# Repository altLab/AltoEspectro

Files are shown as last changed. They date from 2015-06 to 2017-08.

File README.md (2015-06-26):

# AltoEspectro

Projecto de Uma Camara de CCD arrefecida para Espectroscopia, imagem de scanning, ou para fotografia panorâmica se utilizada com cabeça panorâmica.

Assenta no Sensor CCD da Sony ILX 544A com ultra sensibilidade.

Tendo como unidade de génese de sinais, leitura da saída do sensor, controlo do arrefecimento termoeléctrico, e controlo de temperatura o Microcontrolador da Atmel Atmega 328 que faz parte do Arduino Nano.

Notas do projecto podem ser encontradas no MicroSite de Documentação do AltLab 

[aqui](http://altlab.org/d/s/projectos/altspectra/)

Projecto Iniciado por:

- Fernando Carvalho
- JAC
- Luis Dinis
- Pedro Angelo

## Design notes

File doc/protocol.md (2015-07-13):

# AltSpectra serial protocol

The serial protocol uses a request/reply pattern between a host application and the device.

The host application issues commands that are comprised of a request header that identifies the command and an optional request payload (depending on the command)

    <header>[<data>]

The device replies with a reply header that indicates the request status followed by a data payload

    <header><data>

## Device Commands

### Init

Initialises the device

Request data: none <BR>
Reply status: OK/NOK <BR>
Reply data: firmware version <BR>

### Set Timestamp

Sets the internal timestamp

Request data: new timestamp in Julian Day with only the day part, and the time part = 0,500000 <BR>
Reply status: OK/NOK <BR>
Reply data: internaltime <BR>

### Get Spectrum Sample 

Get a spectrum sample from the sensor

Request data: exposure time in milliseconds <BR>
Reply status: OK/NOK <BR>
Reply data: sample timestamp, temperature readings (sensor and heatsink), data samples <BR>

### Halt Spectrum Sample

instructs device to Halt exposure.

Request data: none <BR>
Reply status: OK/NOK <BR>
Reply data: None <BR>

### Get Temperature Sample

Get the temperature values from the device

Request data: none <BR>
Reply status: OK/NOK <BR>
Reply data: temperature readings (sensor and heatsink) <BR>

### Set Temperature

Set the temperature values for the device

Request data: Temperature in Signed Decimal Format with 1 Decimal Digit <BR>
Reply status: OK/NOK <BR>
Reply data: temperature readings (sensor and heatsink) <BR>

### Set Cooling ON/OFF

Set the cooler on or OFF

Request data: "AS+F ON/OFF" <BR>
Reply status: OK/NOK <BR>
Reply data: Cooling Status {ON/OFF}; <BR>

### Get Cooling Status

Get the Cooler Status ON/OFF 

Request data: None <BR>
Reply status: OK/NOK <BR>
Reply data: Cooling Status TRUE:FALSE; <BR>

###Get Status

gets the internal Status of the device

Request data: NULL<BR>
Reply status: OK/NOK <BR>
Reply data: <Version> <timestamp> <coolingtemperature> <heatsinktemperature> <exposing> <cooling> <fan> <BR>

###Set Fan

Sets the Fan ON or OFF

Request data: ON/OFF <BR>
Reply status: OK/NOK <BR>
Reply data: Fan ON/OFF; <BR>

## Text Encoding

### Init

Request: "AS+A"

Reply: "OK firmware version CR "

### Set Timestamp

Request: "AS+B <timestamp>" <BR>
Reply: "OK <timestamp> <CR>" <BR>

### Get Spectrum Sample

Request: "AS+C <exposure time>" <BR>
Reply: "OK <timestamp> <sensor temperature> <heatsink temperature> <exposure> <data0> <data1> ... <data_n> <CR>" <BR>

### Halt Spectrum Sample

Request: "AS+D" <BR>
Reply: OK/NOK <BR>

### Get Temperature Sample

Request: "AS+E" <BR>
Reply: "OK <timestamp> <sensor temperature> <heatsink temperature> <CR>" <BR>

### Set Temperature

Request: "AS+F <sensor temperature>" <BR>
Reply status: OK <sensor temperature> <BR>
Reply data: "OK <sensor temperature> <heatsink temperature> <CR>" <BR>

### Set Cooling ON/OFF

Request data: "<AS+G ON/OFF>" <BR>
Reply status: OK/NOK <BR>
Reply data: "OK <sensor temperature> <heatsink temperature> <CR>" <BR>

### Get Status

Request data: "<AS+H>" <BR>
Reply status: OK/NOK <BR>
Reply data: "OK <version> <timestamp> <sensor temperature> <heatsink temperature> <CR>" <BR>

## Binary Encoding

### Init

Request: 0xA501
Reply: 0xA511 (OK) | 0xA510 (NOK) <firmware version (char / 1 byte)>

### Set Timestamp

Request: 0xA502 <timestamp (long int / 4 bytes)>
Reply: 0xA521 (OK) | 0xA520 (NOK)

### Get Spectrum Sample

Request: 0xA503 <exposure time (long int / 4 bytes)>
Reply: 0xA531 (OK) | 0xA5 (NOK) <timestamp (long int / 4 bytes)> <sensor temperature (short int / 2 bytes)> <heatsink temperature (short int / 2 bytes)> <data0 (short int / 2 bytes)> ... <data_n (short int / 2 bytes)>

### Get Temperature Sample

Request: 0xA504 
Reply: 0xA541 (OK) | 0xA540 (NOK) <sensor temperature (short int / 2 bytes)> <heatsink temperature (short int / 2 bytes)>

### Set Temperature

Request: 0xA505 <sensor temperature>"
Reply status: OK <sensor temperature>
Reply data: "OK <sensor temperature> <heatsink temperature> <CR>"

### Set Cooling ON/OFF

Request data: 0xA506 
Reply status: OK/NOK
Reply data: "OK <sensor temperature> <heatsink temperature> <CR>"

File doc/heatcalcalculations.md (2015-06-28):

#Calculo da capacidade térmica de um dissipador de aluminio:

##requisitos:

- Conductividade térmica do material do dissipador
- volume do dissipador.
- Diferencial de temperatura dos meios em contacto

##introdução

A propriedade intrinseca dos materiais que nos permite compreender como funciona um sistema de arrefecimento. Esta compreensão permite que em cenários complexos construir um sistema de arrefecimento mais ou menos eficiente, se utilizados os materiais correctos da forma correcta.

É necessário compreender que os detalhes ditam o sucesso ou o insucesso, não os ter em conta, reduz o desenho de sistemas de arrefecimento a uma mera adivinhação.

Os sistemas de arrefecimento, obedecem a leis que se podem aproximar a sistemas hidraúlicos na medida em que lidamos com quantidades, que tem de percorrer conductas sólidas, com propriedades que definem fluxos, logo a não compreensão destes fenómenos governadas por estas leis implica, a não realização de sistemas eficientes.

posto isto, coloquemos o contexto da construção de um sistema de arrefecimento para um arrefecedor termoeléctrico, baseado nos dispositivos TEC/Peltier que tiram partido do efeito de Sebbeck.

![Fotografia de um Peltier]()

O Peltier possui um lado quente e um lado frio, o primeiro dissipa o calor retirado do lado frio, criando um diferencial de temperatura, que pode atingir os 85 graus em determinados dispositivos.

A função do dissipador de um sistema destes visa conduzir em primeiro lugar o calor gerado na superficie do Peltier até ao ar que circunda o dispositivo. À priori parecerá simples, apenas temos de colocar um dissipador encostado ao peltier e obteremos a máxima eficiência, nada mais errado, estariamos a abordar o problema de forma ingénua e simplista, ao ponto de deixarmos de lado detalhes tão importantes como: a superficie de contacto, peltier com o dispositivo a arrefecer, entre a superficie a arrefecer e o sensor, o contacto do lado quente do peltier com o dissipador.

Em primeiro lugar é necessário perceber que o ar se encontra na equação em determinados pontos de contacto, pois as superficies por mais polidas que sejam possuem uma rugosidade onde se encontrará um isolante térmico dos mais eficientes, o ar. em segundo lugar se colocarmos um material que aumente a condução térmica, rápidamente reduziremos a resistência ao fluxo de calor. posteriormente, temos de compreender que um fluxo de ar no dissipador, deve ser suficiente para retirar o calor acumulado num dissipador por forma a aumentar a sua eficiência.

contemplemos o Dissipador no seu contacto com o ar, temos um material com um capacidade de condução térmica de aproximadamente 160 W. m-1 K-1, em contacto com um material, o ar, com uma capacidade de condução térmica, baixa, de 0.0262 W.m-1.K-1 logo um conductor térmico e uma fronteira para um isolante térmico, no entanto, é para este isolante térmico que temos que passar o calor. Para aumentar a eficiência desta transferêcia de calor temos de aumentar a razão de transferência, e usualmente esse aumento obtém-se aumentado a velocidade do fluxo de ar que permite retirar maior quantidade de calor. outra abordagem simples passa pelo aumento da superficie de contacto, que em hidráulica significaria o aumento da conduta de transferência, usualmente este concretização obtém com a mudança de um dissipador de laminas para um dissipador de pinos, ao duplicar a área do dissipador duplica-se a taxa de transferência de calor.

##Escolha do material do cold Finger:

A escolha do material do cold finger, foi realizada comparando os materiais disponíveis, cobre e aluminio, se à priori pareceria que o aluminio se apresentaria como um bom candidato, rápidamente ficou relegado para segundo lugar pela capacidade que possui de transmitir calor como se pode ver na tabela apresentada em 
[1].

Comparando a conductividade térmica de ambos se compreende que para o aluminio temos uma conductividade térmica de 249 W. m-1 Kelvin -1 e que para o Cobre temos um valor de 368 W.m-1.K-1, estando apenas a ter em linha de conta materiais puros, se pesquisarmos diferentes materiais disponíveis no mercado, concluimos que dependendo do grau de pureza da liga disponivel para aquisição temos ainda piores valores de conductividade térmica. Mamtém-se no entanto, o diferencial, ficando o cobre sempre na dianteira.

nesta comparação apenas compreendemos ser o cobre o elemento de eleição para a condução térmica do calor no caso do coldfinger, e no dissipador, no entanto a escolha deste elemento para o dissipador iria onerar muito os custos de produção de um dispositivo, como o que actualmente se encontra em desenvolvimento.

Compreender o Processo de transferência térmica e os factores que o influênciam:

Os factores que influênciam a transferência de calor são:

- Temperatura ambiente
- Humidade 
- Pressão Atmosférica.
- velocidade do Ar no dissipador
- Eficiência térmica do Peltier
- Eficiência térmica do conjunto de dissipação.

##Referências:

- [1] Listas de conductividades térmicas - https://en.wikipedia.org/wiki/List_of_thermal_conductivities
- Conversão de Watt para Joule - http://www.rapidtables.com/convert/electric/Watt_to_Joule.htm
- Conversãod e Joule para Grau Celsius - http://www.convertunits.com/from/joule/to/celsius+heat+unit
- peltier Guide - http://www.heatsink-guide.com/peltier.htm
- Thermoelectric Cooling - https://en.wikipedia.org/wiki/Thermoelectric_cooling
- Thermal Design - http://www.smps.us/thermal.html
- Novel Concept Heat Sink CFD Simulations . http://www.novelconceptsinc.com/heat-sinks.htm

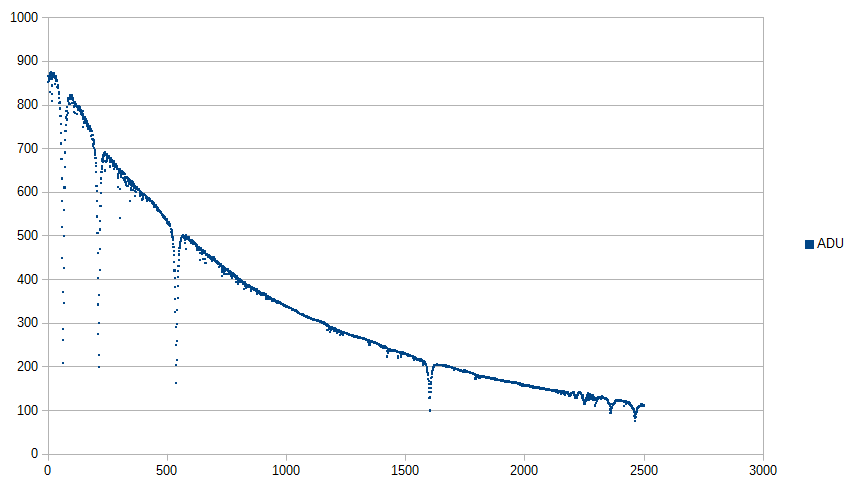
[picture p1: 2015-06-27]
doc/SampleData.png

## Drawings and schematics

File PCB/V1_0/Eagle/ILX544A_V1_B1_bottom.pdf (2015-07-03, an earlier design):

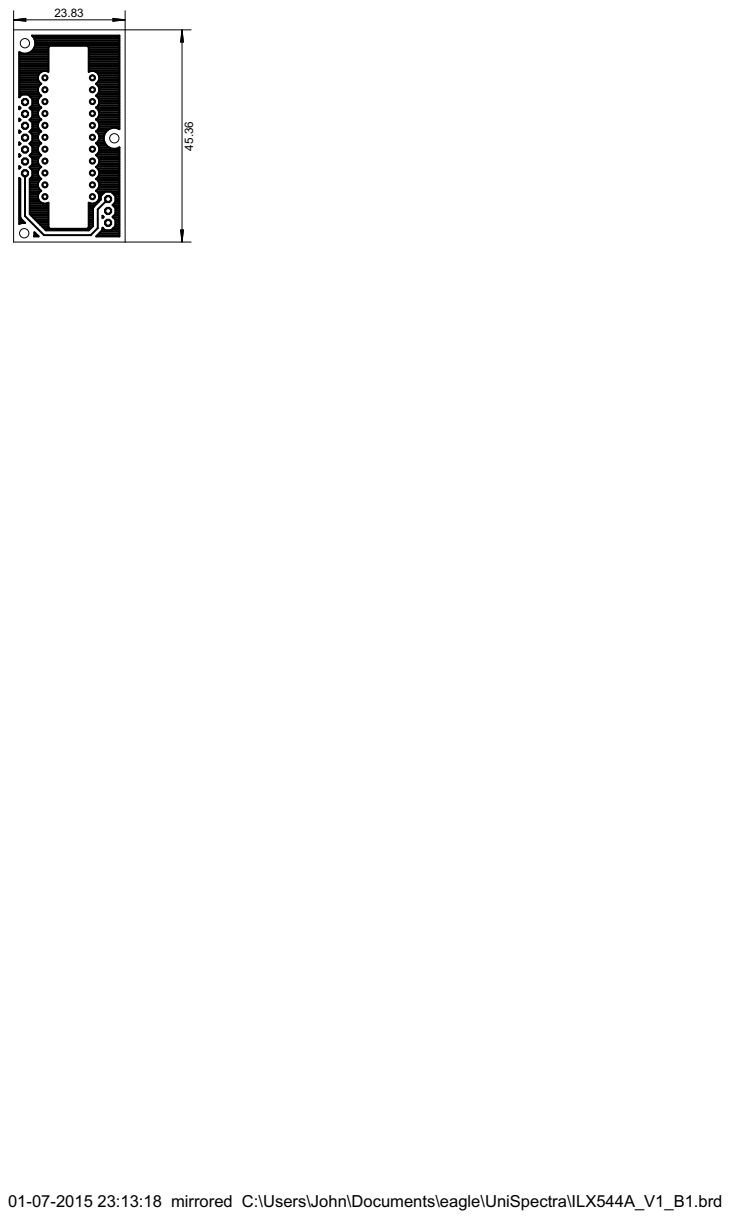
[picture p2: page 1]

01-07-2015 23:13:18 mirrored C:\Users\John\Documents\eagle\UniSpectra\ILX544A_V1_B1.brd

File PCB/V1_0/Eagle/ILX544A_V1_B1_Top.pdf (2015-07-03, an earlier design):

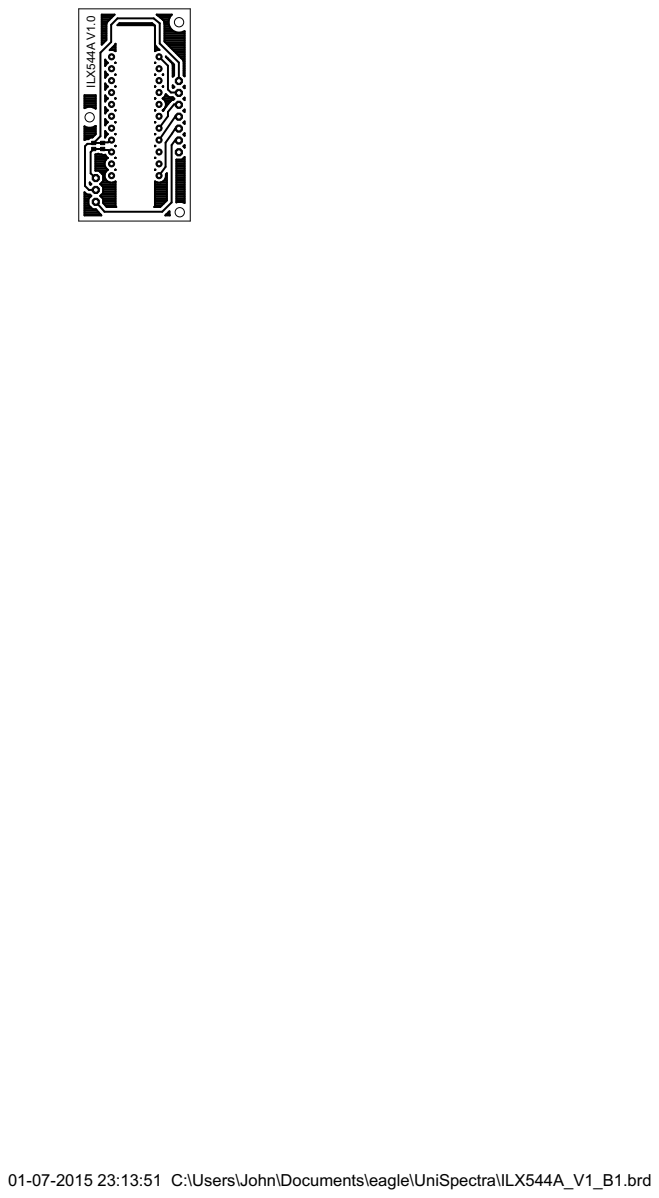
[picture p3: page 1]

01-07-2015 23:13:51 C:\Users\John\Documents\eagle\UniSpectra\ILX544A_V1_B1.brd

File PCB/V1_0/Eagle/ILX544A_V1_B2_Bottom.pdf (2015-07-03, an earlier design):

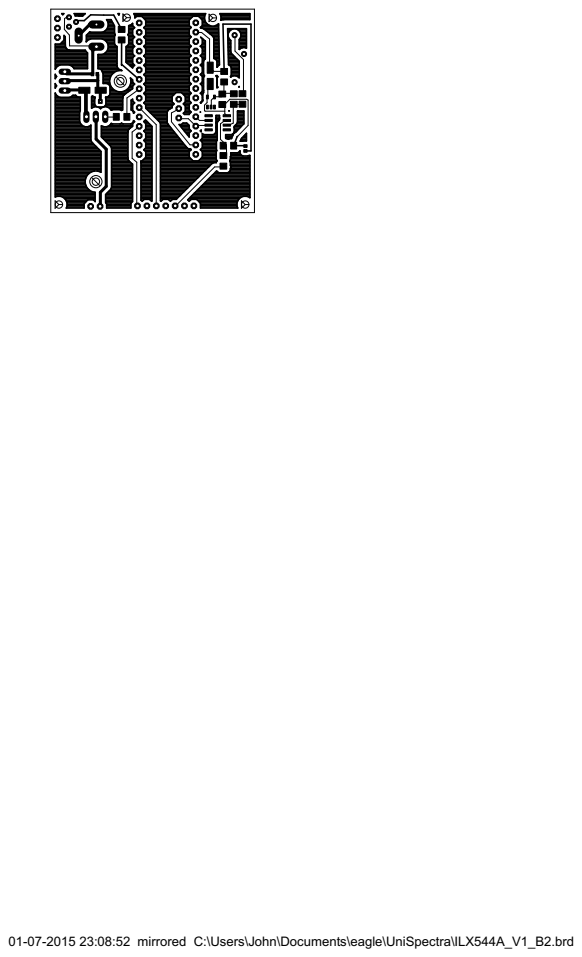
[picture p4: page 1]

01-07-2015 23:08:52 mirrored C:\Users\John\Documents\eagle\UniSpectra\ILX544A_V1_B2.brd

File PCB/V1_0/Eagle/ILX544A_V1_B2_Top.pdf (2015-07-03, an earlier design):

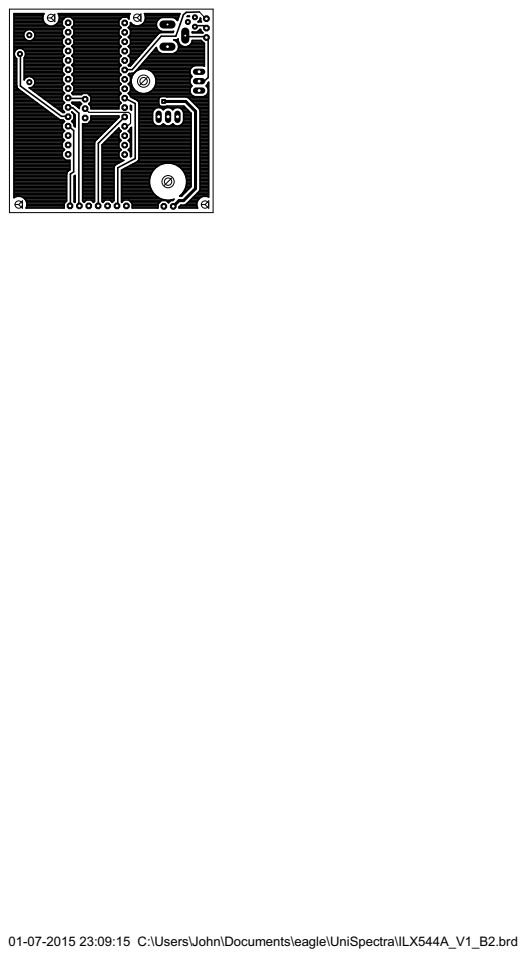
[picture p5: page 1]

01-07-2015 23:09:15 C:\Users\John\Documents\eagle\UniSpectra\ILX544A_V1_B2.brd

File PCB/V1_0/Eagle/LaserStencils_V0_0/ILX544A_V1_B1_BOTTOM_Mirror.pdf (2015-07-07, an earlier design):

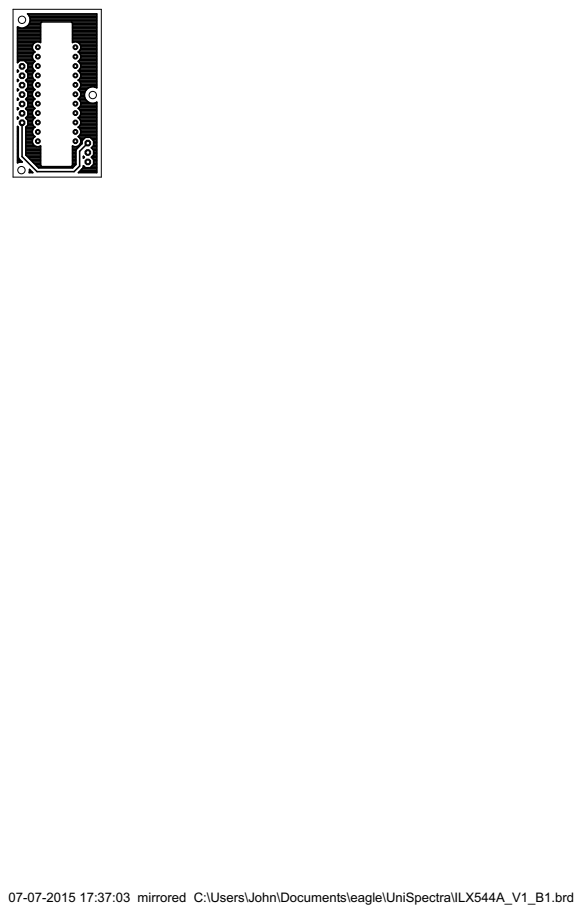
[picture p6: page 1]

07-07-2015 17:37:03 mirrored C:\Users\John\Documents\eagle\UniSpectra\ILX544A_V1_B1.brd

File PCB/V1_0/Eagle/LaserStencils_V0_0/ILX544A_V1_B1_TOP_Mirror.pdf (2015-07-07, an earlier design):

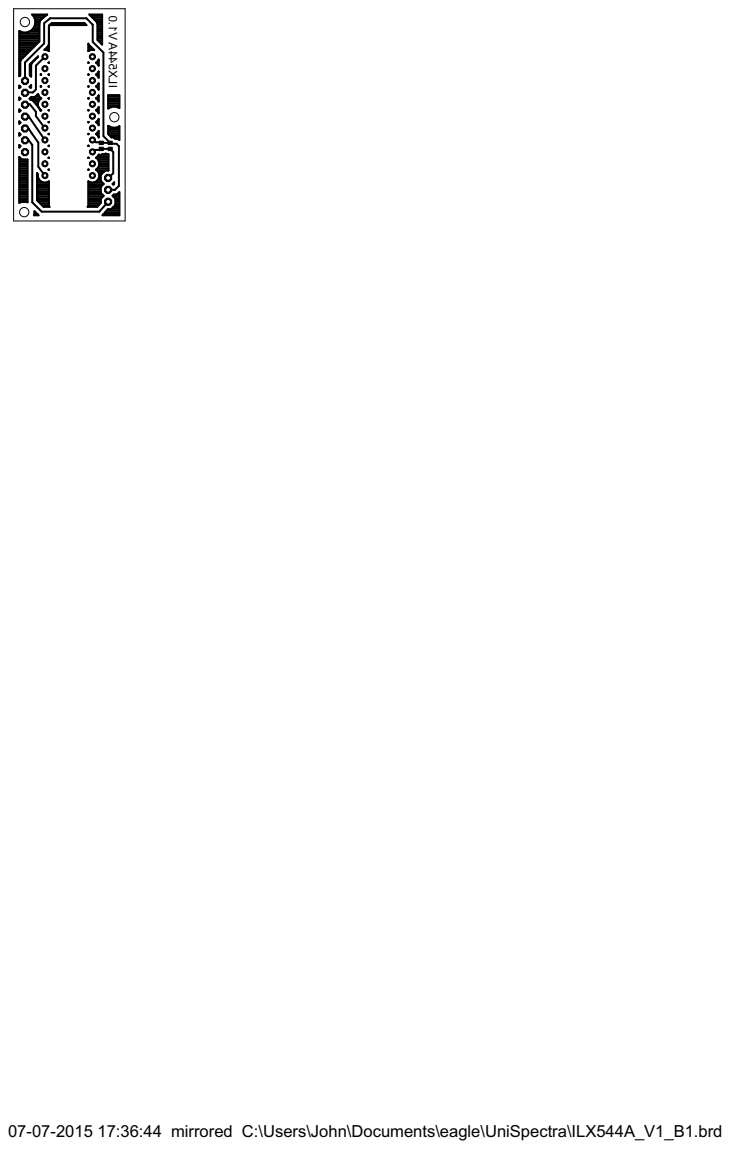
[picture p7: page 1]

07-07-2015 17:36:44 mirrored C:\Users\John\Documents\eagle\UniSpectra\ILX544A_V1_B1.brd

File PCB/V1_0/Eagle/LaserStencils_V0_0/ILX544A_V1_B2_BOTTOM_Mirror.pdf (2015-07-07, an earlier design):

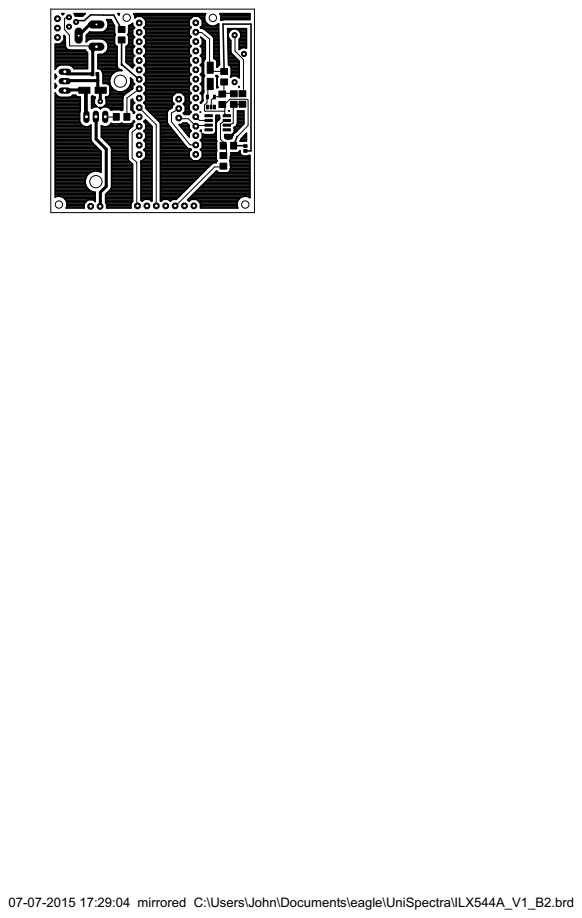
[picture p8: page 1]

07-07-2015 17:29:04 mirrored C:\Users\John\Documents\eagle\UniSpectra\ILX544A_V1_B2.brd

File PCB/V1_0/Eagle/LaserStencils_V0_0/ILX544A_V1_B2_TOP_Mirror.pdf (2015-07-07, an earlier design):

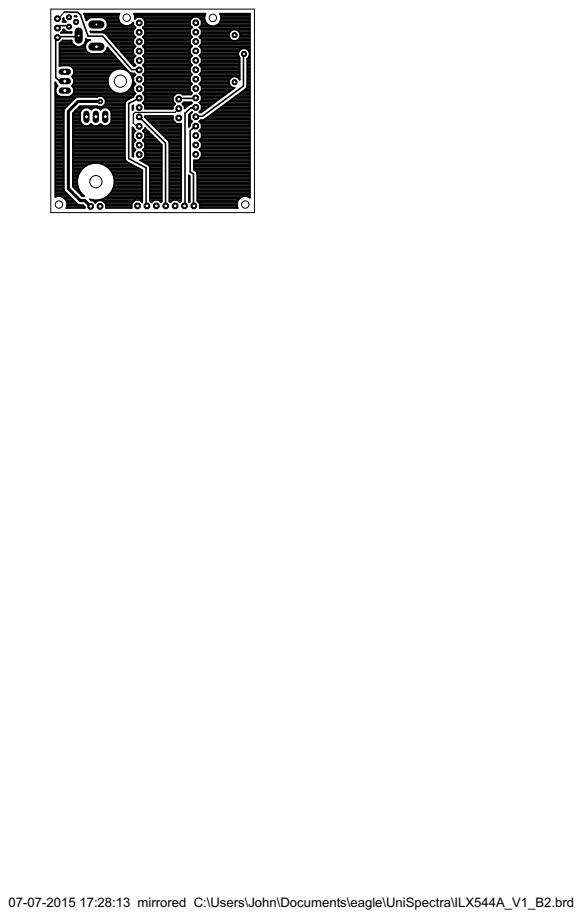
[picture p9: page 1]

07-07-2015 17:28:13 mirrored C:\Users\John\Documents\eagle\UniSpectra\ILX544A_V1_B2.brd

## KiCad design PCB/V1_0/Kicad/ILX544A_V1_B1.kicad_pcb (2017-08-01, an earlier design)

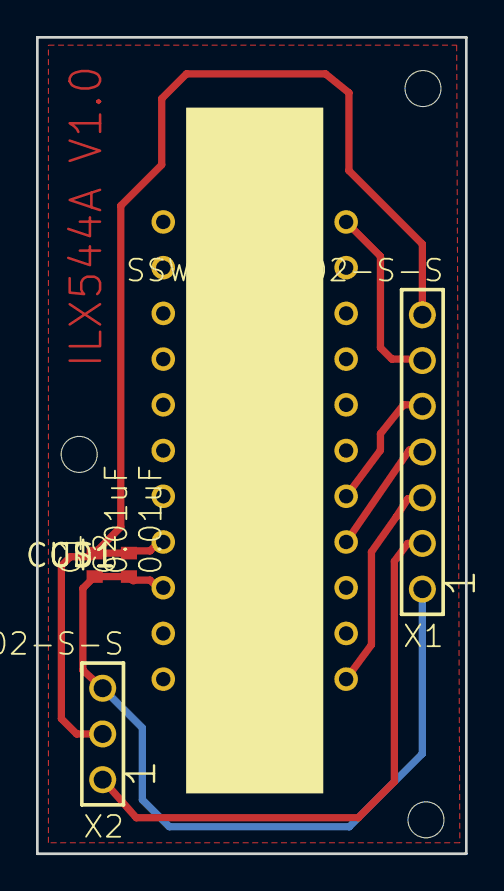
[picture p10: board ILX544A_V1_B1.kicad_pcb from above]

Board: 2 copper layers, 23.8 x 45.4 mm, 8 parts (0 on the bottom side), 7 nets.

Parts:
@HOLE0, @HOLE1, @HOLE2: (no value)
C1, C2: 0.01uF; C0402
U$1: CCD1; ILX544A
X1: SSW-107-02-S-S
X2: SSW-103-02-S-S

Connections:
unnamed: C1.1, C2.1, U$1.P$20, X1.1, X2.3
unnamed: U$1.P$1, X1.3
unnamed: U$1.P$4, X1.4
unnamed: X1.2, X2.1
unnamed: U$1.P$11, X1.6
unnamed: U$1.P$5, X1.5
unnamed: C1.2, C2.2, U$1.P$19, X1.7, X2.2

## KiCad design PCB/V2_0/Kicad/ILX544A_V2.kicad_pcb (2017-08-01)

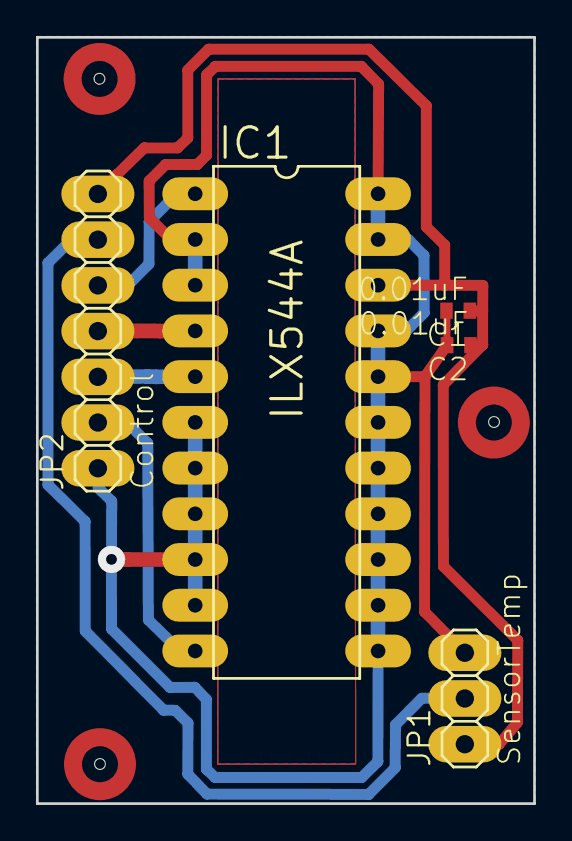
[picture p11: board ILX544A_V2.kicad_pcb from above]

Board: 2 copper layers, 27.6 x 42.6 mm, 8 parts (0 on the bottom side), 7 nets.

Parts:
@HOLE0, @HOLE1, @HOLE2: (no value)
C1, C2: 0.01uF; C0402
IC1: ILX544A; DIL22-4
JP1: SensorTemp; 1X03
JP2: Control; 1X07

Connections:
unnamed: IC1.5, JP2.3
unnamed: C1.1, C2.1, IC1.20, JP1.1, JP2.7
unnamed: IC1.1, JP2.5
unnamed: IC1.4, JP2.4
unnamed: IC1.11, JP2.2
unnamed: JP1.2, JP2.6
unnamed: C1.2, C2.2, IC1.2, IC1.3, IC1.6, IC1.7, IC1.8, IC1.9, IC1.10, IC1.12, IC1.13, IC1.14, IC1.15, IC1.16, IC1.17, IC1.18, IC1.19, IC1.21, IC1.22, JP1.3, JP2.1

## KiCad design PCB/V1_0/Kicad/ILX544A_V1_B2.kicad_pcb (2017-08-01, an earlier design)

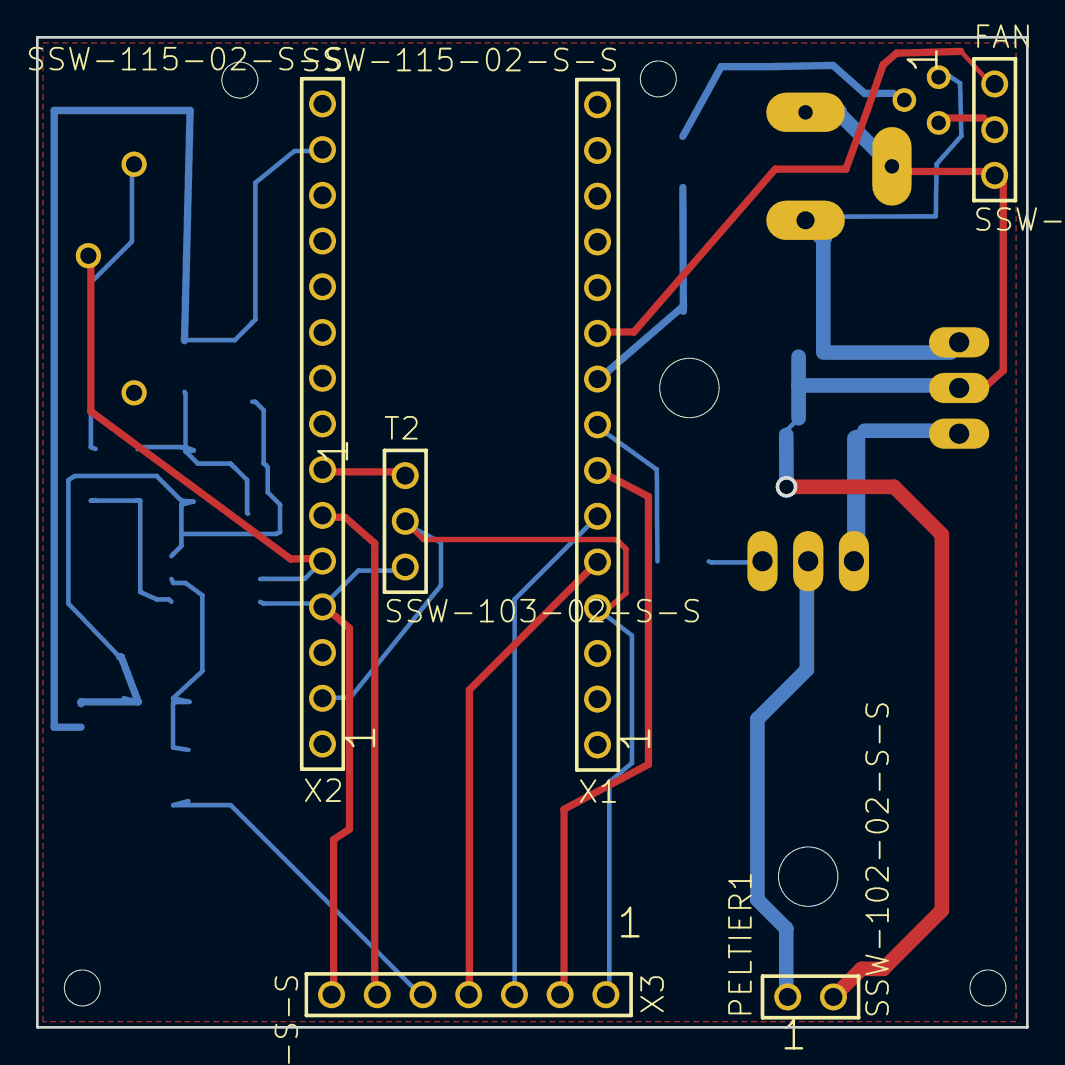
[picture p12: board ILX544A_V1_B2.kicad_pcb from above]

Board: 2 copper layers, 55.0 x 55.0 mm, 29 parts (0 on the bottom side), 25 nets.

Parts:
@HOLE0, @HOLE1, @HOLE2, @HOLE3: (no value)
C1, C4: 22uF; 153CLV-0505
C2, C3: 10nF; C0402
FAN: SSW-103-02-S-S
IC1: 7805T; TO220H
P1: 2k; RTRIM43P
PELTIER1: SSW-102-02-S-S
Q1: BC517; TO92
Q3: TIP125; TO220
R1: 10; R1206
R2: 100K; R1206
R3: 2K9; R1206
R4: 1K; R1206
R5: 100; R1206
R6, R7, R8: 330; R1206
S1: S1; SPC4077
T2: SSW-103-02-S-S
U1: OPA350UA; SOIC127P600X175-8N
U$1: TL1; TL431CDBVRE4
X1, X2: SSW-115-02-S-S
X3: SSW-107-02-S-S

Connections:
GND: C1.-, C2.2, R2.1, R4.2, U1.4, U$1.REF
unnamed: P1.3, R5.1
unnamed: R3.1, R5.2, U1.2
unnamed: R1.1, R2.2, U1.3
unnamed: R3.2, R4.1, R6.2
unnamed: P1.2, U1.6, X2.5
unnamed: C3.1, IC1.1, Q1.3, S1.3
unnamed: C4.+, IC1.3, Q3.3
unnamed: R1.2, X3.5
unnamed: PELTIER1.1, Q3.2
unnamed: C3.2, C4.-, FAN.3, IC1.2, PELTIER1.2, S1.1, S1.2
unnamed: X2.6, X3.6
unnamed: Q3.1, R7.1
unnamed: X1.5, X3.4
unnamed: X1.6, X3.3
unnamed: X1.7, X3.2
unnamed: C1.+, C2.1, R6.1, X2.14
unnamed: FAN.2, Q1.1
unnamed: R7.2, X1.8
unnamed: FAN.1, X1.10
unnamed: Q1.2, R8.1
unnamed: R8.2, X1.9
unnamed: T2.2, X1.4, X2.2, X3.1
unnamed: T2.1, X2.7
VCC: T2.3, U1.7, X2.4, X3.7

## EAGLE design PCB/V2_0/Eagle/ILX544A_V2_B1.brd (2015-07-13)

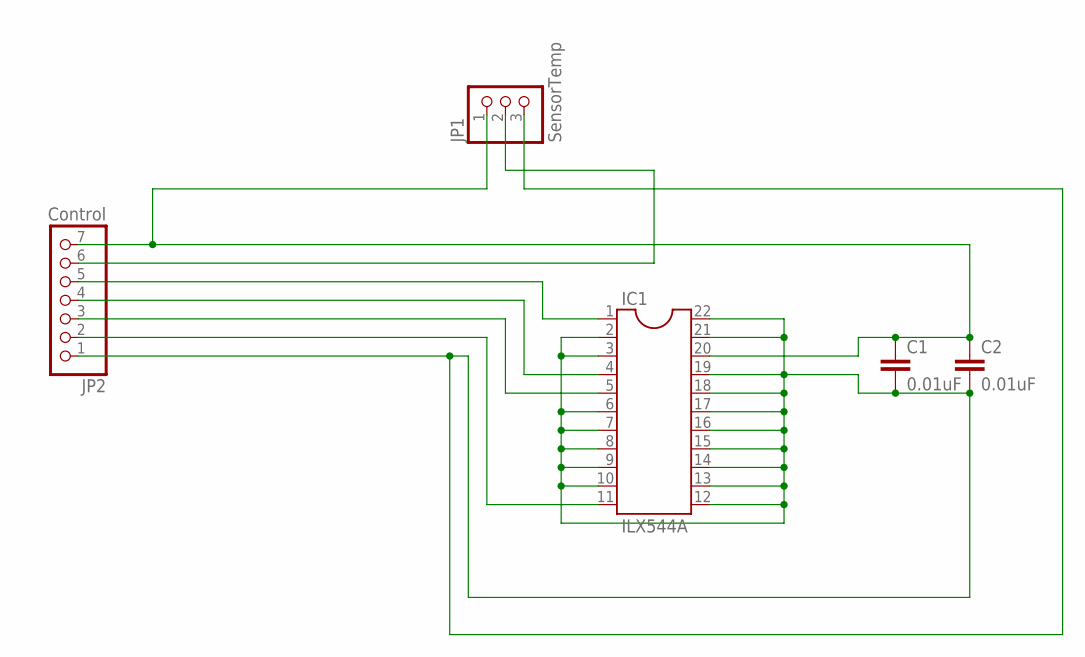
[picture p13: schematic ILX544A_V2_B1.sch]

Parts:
C1, C2: 0.01uF; C0402
IC1: ILX544A; DIL22-4
JP1: SensorTemp; 1X03
JP2: Control; 1X07

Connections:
unnamed: IC1.5, JP2.3
unnamed: C1.1, C2.1, IC1.20, JP1.1, JP2.7
unnamed: IC1.1, JP2.5
unnamed: IC1.4, JP2.4
unnamed: IC1.11, JP2.2
unnamed: JP1.2, JP2.6
unnamed: C1.2, C2.2, IC1.2, IC1.3, IC1.6, IC1.7, IC1.8, IC1.9, IC1.10, IC1.12, IC1.13, IC1.14, IC1.15, IC1.16, IC1.17, IC1.18, IC1.19, IC1.21, IC1.22, JP1.3, JP2.1

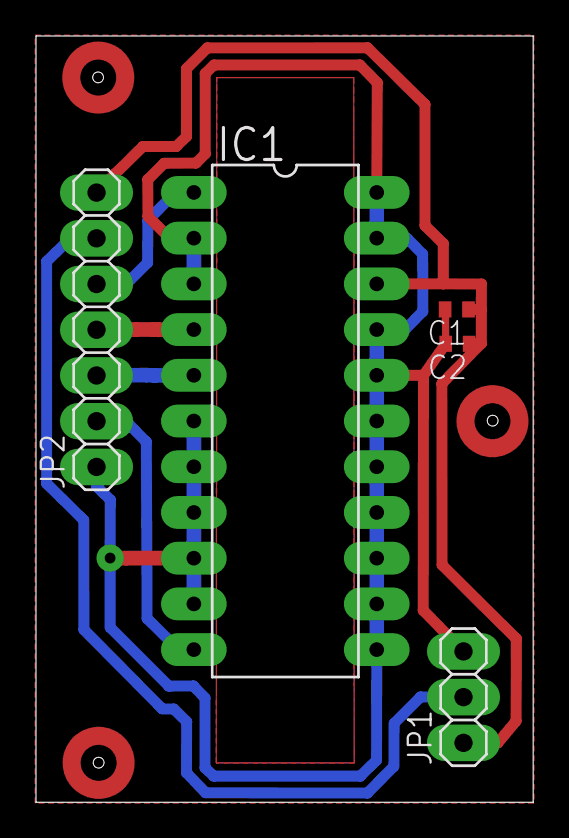
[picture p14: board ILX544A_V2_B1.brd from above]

Board: 2 copper layers, 27.6 x 42.6 mm, 5 parts (0 on the bottom side), 7 nets.

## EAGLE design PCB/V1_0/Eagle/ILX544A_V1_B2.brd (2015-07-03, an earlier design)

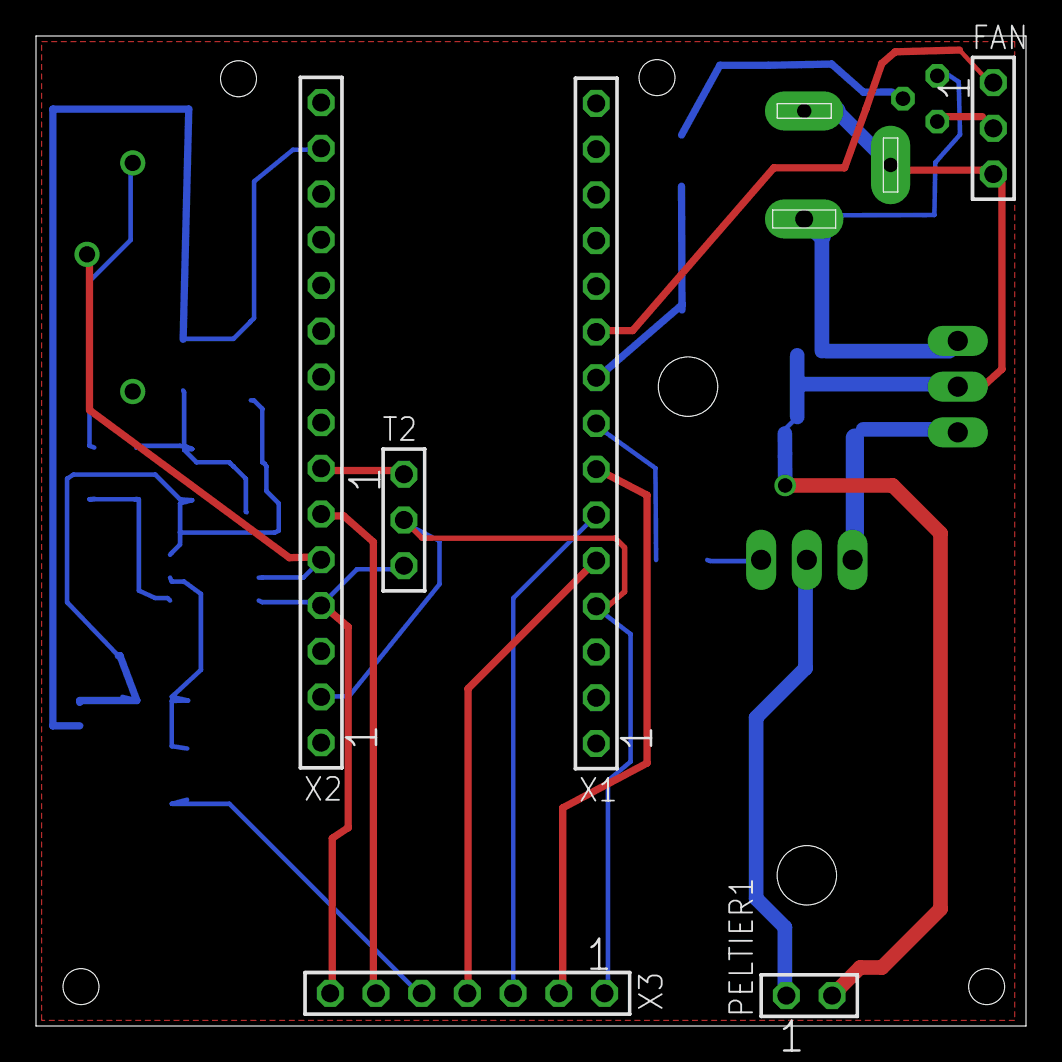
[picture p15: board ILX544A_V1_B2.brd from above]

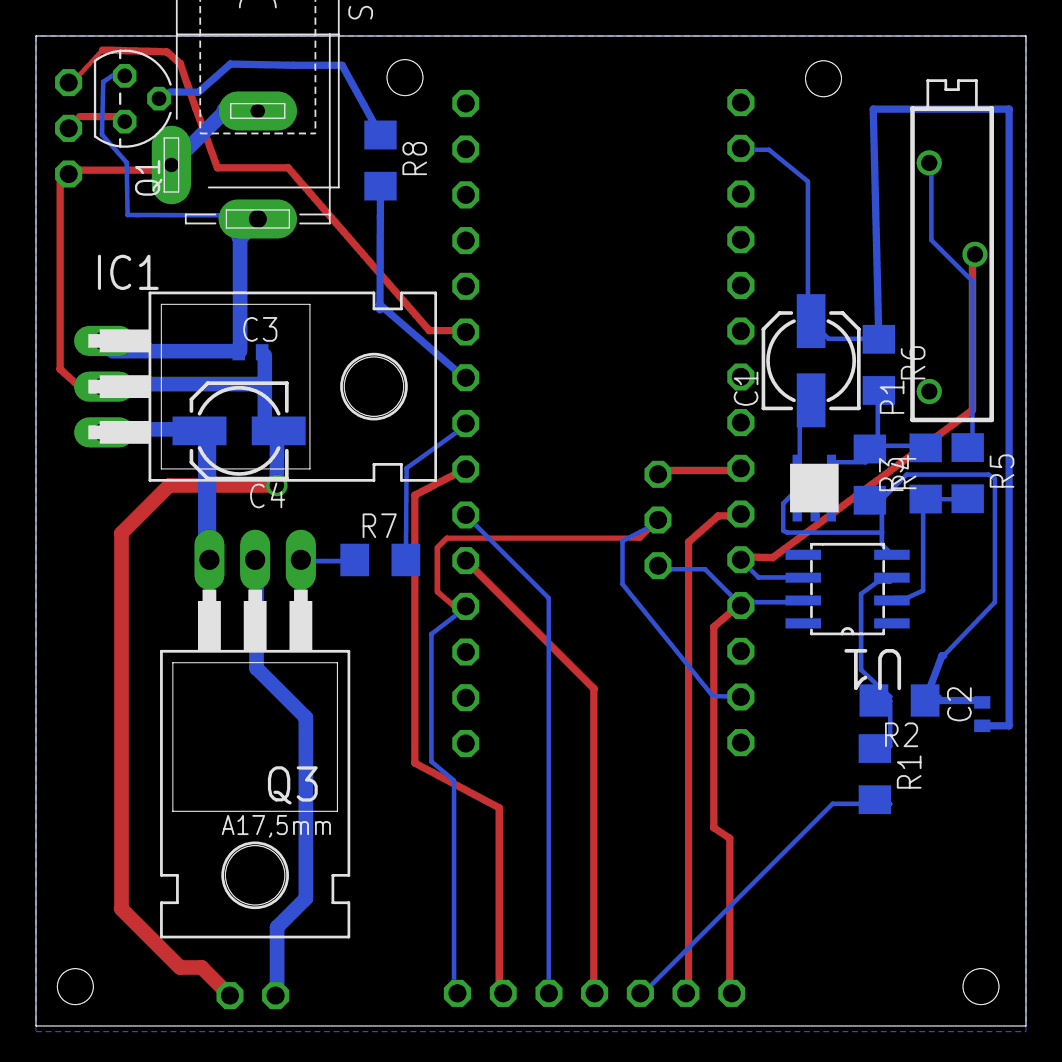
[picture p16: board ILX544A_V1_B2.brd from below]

Board: 2 copper layers, 55.0 x 55.0 mm, 25 parts (19 on the bottom side), 25 nets.

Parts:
C1, C4: 22uF; 153CLV-0505
C2, C3: 10nF; C0402
FAN: SSW-103-02-S-S
IC1: 7805T; TO220H
P1: 2k; RTRIM43P
PELTIER1: SSW-102-02-S-S
Q1: BC517; TO92
Q3: TIP125; TO220
R1: 10; R1206
R2: 100K; R1206
R3: 2K9; R1206
R4: 1K; R1206
R5: 100; R1206
R6, R7, R8: 330; R1206
S1: S1; SPC4077
T2: SSW-103-02-S-S
U1: OPA350UA; SOIC127P600X175-8N
U$1: TL1; TL431CDBVRE4
X1, X2: SSW-115-02-S-S
X3: SSW-107-02-S-S

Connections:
GND: C1.-, C2.2, R2.1, R4.2, U1.4, U$1.REF
unnamed: P1.3, R5.1
unnamed: R3.1, R5.2, U1.2
unnamed: R1.1, R2.2, U1.3
unnamed: R3.2, R4.1, R6.2, U$1.ANODE, U$1.CATODE
unnamed: P1.2, U1.6, X2.5
unnamed: C3.1, IC1.1, Q1.3, S1.3
unnamed: C4.+, IC1.3, Q3.3
unnamed: R1.2, X3.5
unnamed: PELTIER1.1, Q3.2
unnamed: C3.2, C4.-, FAN.3, IC1.2, PELTIER1.2, S1.1, S1.2
unnamed: X2.6, X3.6
unnamed: Q3.1, R7.1
unnamed: X1.5, X3.4
unnamed: X1.6, X3.3
unnamed: X1.7, X3.2
unnamed: C1.+, C2.1, R6.1, X2.14
unnamed: FAN.2, Q1.1
unnamed: R7.2, X1.8
unnamed: FAN.1, X1.10
unnamed: Q1.2, R8.1
unnamed: R8.2, X1.9
unnamed: T2.2, X1.4, X2.2, X3.1
unnamed: T2.1, X2.7
VCC: T2.3, U1.7, X2.4, X3.7

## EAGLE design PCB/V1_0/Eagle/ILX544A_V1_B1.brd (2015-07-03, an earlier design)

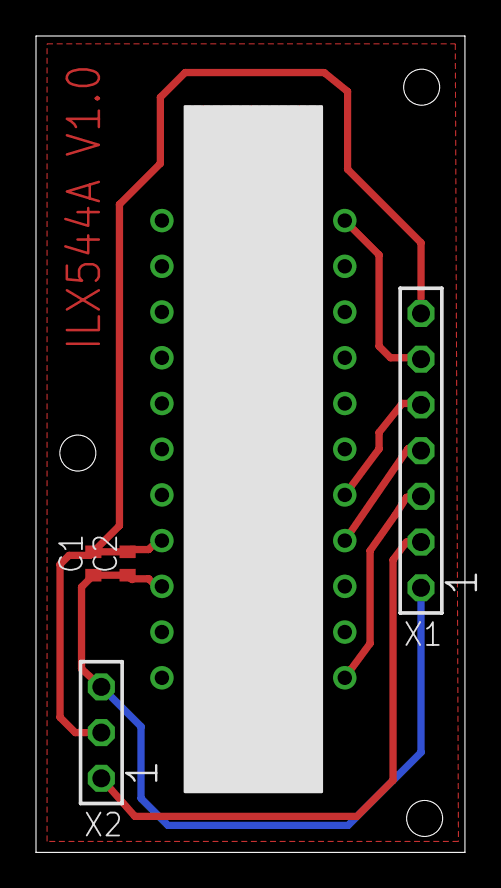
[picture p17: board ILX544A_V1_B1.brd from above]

Board: 2 copper layers, 23.8 x 45.4 mm, 5 parts (0 on the bottom side), 7 nets.

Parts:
C1, C2: 0.01uF; C0402
U$1: CCD1; ILX544A
X1: SSW-107-02-S-S
X2: SSW-103-02-S-S

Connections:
unnamed: U$1.P$5, X1.5
unnamed: U$1.P$1, X1.3
unnamed: U$1.P$4, X1.4
unnamed: C1.1, C2.1, U$1.P$20, X1.1, X2.3
unnamed: U$1.P$11, X1.6
unnamed: X1.2, X2.1
unnamed: C1.2, C2.2, U$1.P$19, X1.7, X2.2

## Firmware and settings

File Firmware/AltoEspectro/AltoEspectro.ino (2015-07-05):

/*
 *
When pin 4 of the ILX544A
- is connected to the 5V VCC the Sensor works in Store and Wipe Mode
- is connected to the ground the Sensor works in Store and Hold Mode
ADC
usualy the Atmega takes 13 adc Clock pulses to make a readout.
with a prescaler of 128 the adc clock is running at 125  Khz at this clock each readout takes 104uS
with a prescaler of 16  the adc clock is running at 1000 KHz the readout takes 13  uS
with a prescaler of 8   the adc clock is running at 2000 Khz the readout takes 6.5 uS

*/

#define FOSC 16000000

#ifndef F_CPU
#define F_CPU 1600000UL
#endif

#define Mode 0          //Default Mode 0 = Text; Mode 1 = binary

#define ROG  PORTB0     //Port used for the Release of Gate - pin8 in Arduino Uno
#define CLK  PORTB1     //Port used for the clock - Pin9 in Arduino Uno
#define SH PORTB2       //Port used for the Store and Hold - pin10
#define COOLING PORTB3  //Port used for the digital IO for the Peltier Circuit

#define FAN PORTD6      //Port used for the PWM Controling of the Fan

#define BAUD 9600
//#define USART_BAUDARATE 38400
#define UBRR_VALUE (FOSC/(16*BAUD))-1


#define VER "0_3_3"

//ILX544A signal sequence
#define dsignal1 12
#define opticalblack 18
#define dsignal2 2

#define pixelcount 2048
//uint16_t pixelcount = 2048;

#define dsignal3 12
#define clockdelay 1   //the time that the pulse is keept Low or High in microseconds

long exposure = 0;

//timestamp global variable used to timestamp the exposures
unsigned long timestamp = 0;

#define ADC_CCD 0
#define ADC_peltier 1
#define ADC_heatsink 2

float peltiertemp = 0;
float heatsinktemp = 0;

//ROG and ClK Pulse typical is 5000 nS or 5 uS
//432Khz delay = 1uS
//262Khz delay = 2uS
//171Khz delay = 3uS
//127Khz delay = 4uS
//100Khz delay = 5uS

//Counters for the Cycles
uint8_t start_counter = 0;
uint8_t dsignal1_counter = 0;
uint8_t opticalblack_counter = 0;
uint8_t dsignal2_counter = 0;
uint16_t pixelcount_counter = 0;
uint8_t dsignal3_counter = 0;

#define buffersize 12
char value[4];


uint16_t sensorValue = 0;

uint16_t counter = 0;

char data;
char command[buffersize];

unsigned long ellapsedtime = 0;
unsigned long starttime = 0;


#include <SoftwareSerial.h>
#include <stdio.h>
#include <avr/interrupt.h>
#include <avr/io.h>
#include <util/delay.h>
#include <HardwareSerial.h>
#include <inttypes.h>
#include <util/setbaud.h>
#include <stdlib.h>
//#include <stdbool.h>
//#include <avr/pgmspace.h>

#include "commands.h"


void InitADC()
{
  //analog Ref on Pin 20 = 4.89V for USB power

  // TODO Constant to correct value

  //select VRef = AVCC
  ADMUX |= (1 << REFS0);
  //set the Prescaler to 8 and enable ADC with a prescaler of 8 the
  //adc frequency will be at 2 000 000 Hz
  /*
  Division Factor 2 2 4 8 16 32 64 128
  adsps2          0 0 0 0  1  1  1  1
  adsps1          0 0 1 1  0  0  1  1
  adsps0          0 1 0 1  0  1  0  1
  */
  ADCSRA |= (1 << ADEN) | (0 << ADPS2) | (1 << ADPS1) | (1 << ADPS0);

}

uint16_t ReadADC(uint8_t ADCchannel)
{
  ADCchannel &= 0b00000111; //and op with 7
  //select ADC channel with safety mask
  ADMUX = (ADMUX & 0xF8) | ADCchannel;
  //single conversion mode
  ADCSRA |= (1 << ADSC);
  // wait until ADC conversion is complete
  while ( ADCSRA & (1 << ADSC) );
  return (ADC);
}

void USART_Init( unsigned int baud )
{
  //Disable power consumption Mode by setting PRUSART Register to 0
  (0 << PRUSART0);
  UBRR0H = (unsigned char)(UBRR_VALUE >> 8);
  UBRR0L = (unsigned char) UBRR_VALUE;
  /* Setting the XCKn port pin as output, enables master
  mode. */
  //XCK0_DDR |= (1<<XCK0);
  /* Set MSPI mode of operation and SPI data mode 0. */
  UCSR0C = (0 << UMSEL01) | (1 << UMSEL00) | (0 << UCPHA0) | (0 << UCPOL0);
  /* Enable receiver and transmitter. */
  UCSR0B = (1 << RXEN0) | (1 << TXEN0);
  /* Enable frame format */
  UCSR0C = (1 << USBS0) | (3 << UCSZ00);
  /* Set baud rate. */
  /* IMPORTANT: The Baud Rate must be set after the
  transmitter is enabled */
  UBRR0 = baud;
}


void USART_Transmit(char data)
{
  /* Wait for empty transmit buffer */
  while ( !( UCSR0A & (1 << UDRE0)) )
    ;
  /* Put data into buffer, sends the data */
  UDR0 = data;
}

unsigned char USART_Receive(void)
{
  while (!(UCSR0A) & (1 << RXC0));
  return UDR0;
}



void USART_Transmit_S(char *str)
{
  while (*str)
  {
    USART_Transmit(*str);
    str++;
  }
}

void USART_Transmit_uint16(uint16_t value16)
{
  char char1 = value16 & 0xFF;
  char char2 = value16 >> 8;
  USART_Transmit(char1);
  USART_Transmit(char2);

}

void senddata(uint16_t _sensorValue)
{

  // itoa(_sensorValue,value,4);  //Convert the sensor value to a char array
  sprintf(value, "%u", _sensorValue); // format it to be printed as a str
  USART_Transmit_S(value);
  USART_Transmit_S("\r\n");
}

void getexposure()
{

  //Initial Release of Gate
  _delay_us(clockdelay);
  PORTB = (1 <<  ROG) | (1 << CLK)  ; // 0
  _delay_us(clockdelay);
  PORTB = (1 <<  ROG) | (1 << CLK)  ; // 0
  _delay_us(clockdelay);
  PORTB = (1 <<  ROG) | (0 << CLK)  ; // 1
  _delay_us(clockdelay);
  PORTB = (1 <<  ROG) | (1 << CLK)  ; // 2
  _delay_us(clockdelay);
  PORTB = (1 <<  ROG) | (1 << CLK)  ; // 3
  _delay_us(clockdelay);
  PORTB = (0 <<  ROG) | (1 << CLK)  ; // 4
  _delay_us(clockdelay);
  PORTB = (0 <<  ROG) | (1 << CLK)  ; // 5
  _delay_us(clockdelay);
  PORTB = (0 <<  ROG) | (1 << CLK)  ; // 6
  _delay_us(clockdelay);
  PORTB = (1 <<  ROG) | (1 << CLK)  ; // 7
  _delay_us(clockdelay);
  PORTB = (1 <<  ROG) | (1 << CLK)  ; // 8
  _delay_us(clockdelay);
  PORTB = (1 <<  ROG) | (1 << CLK)  ; // 9
  _delay_us(clockdelay);

  //Process the dummy Signalare 12 clock cycles
  do
  {
    PORTB = (1 <<  ROG) | (0 << CLK)  ; // 7
    _delay_us(clockdelay);
    PORTB = (1 <<  ROG) | (1 << CLK)  ; // 7
    dsignal1_counter++;
  } while (dsignal1_counter < dsignal1);

  //process optical black pixels 18 clock cycles
  do
  {
    PORTB = (1 <<  ROG) | (0 << CLK)  ; // 7
    _delay_us(clockdelay);
    PORTB = (1 <<  ROG) | (1 << CLK)  ; // 7
    _delay_us(clockdelay);
    opticalblack_counter++;
  } while (opticalblack_counter < opticalblack);


  //process two extra dummy signals
  do {
    PORTB = (1 <<  ROG) | (0 << CLK)  ; // 7
    _delay_us(clockdelay);
    PORTB = (1 <<  ROG) | (1 << CLK)  ; // 7
    _delay_us(clockdelay);
    dsignal2_counter++;
  } while (dsignal2_counter < dsignal2);


  //process 2048 signals
  //don't forget that the ADC takes 13uS to process the Analog to digital conversion
  // or not
  do {
    PORTB = (1 <<  ROG) | (0 << CLK)  ;
    sensorValue = ReadADC(0);
    //Prototype function to send bytes instead of chars
    //      USART_Transmit_uint16(sensorValue);
    //Prototype function to send chars
    senddata(0);
    _delay_us(clockdelay);

    PORTB = (1 <<  ROG) | (1 << CLK)  ;
    sensorValue = ReadADC(0);
    //Prototype function to send bytes instead of chars
    //      USART_Transmit_uint16(sensorValue);
    //Prototype function to send chars
    senddata(sensorValue);
    _delay_us(clockdelay);

    pixelcount_counter++;
  } while (pixelcount_counter < pixelcount);


  //process two extra dummy signals
  do {
    PORTB = (1 <<  ROG) | (0 << CLK)  ; // 7
    _delay_us(clockdelay);
    PORTB = (1 <<  ROG) | (1 << CLK)  ; // 7
    _delay_us(clockdelay);

    dsignal3_counter++;
  } while (dsignal3_counter < dsignal3);



  dsignal1_counter = 0;
  opticalblack_counter = 0;
  dsignal2_counter = 0;
  pixelcount_counter = 0;
  dsignal3_counter = 0;


}


uint16_t sensortemp() {
  //var
  uint16_t temp = 0;
  temp = ReadADC(1);
  return temp;
}

void updateTemp()
{
  peltiertemp = ReadADC(ADC_peltier);
  heatsinktemp = ReadADC(ADC_heatsink);
}

void processtextmodecommand(char* data)
{
  switch (data[3])
  {
    case INIT_T:
      USART_Transmit_S(NACK);
      USART_Transmit(SPACE);
      USART_Transmit_S(VER);
      USART_Transmit(CR);
      break;

    case SET_TIMESTAMP_T:
      USART_Transmit_S(NACK);
      USART_Transmit(SPACE);
      USART_Transmit(SET_TIMESTAMP_T);
      USART_Transmit_S(data);
      break;

    case GET_SPECTRUMSAMPLE_T:
      USART_Transmit_S("#1");
      getexposure();
      USART_Transmit_S("#2");
      break;
    default:
      break;
  }
}

void processbinmodecommand(char* data)
{
  switch (data[3])
  {
    case INIT_B:
      USART_Transmit_S(NACK);
      USART_Transmit_S(VER);
      USART_Transmit_S("\r\n");
      break;

    case SET_TIMESTAMP_B:
      USART_Transmit_S("B");
      USART_Transmit_S(data);
      break;

    case GET_SPECTRUMSAMPLE_B:
      USART_Transmit_S("#1");
      getexposure();
      USART_Transmit_S("#2");
      break;
    default:
      break;
  }
}

void processcommand(char* _data)
{
  if (!Mode)
  {
    processtextmodecommand(_data);
  }
  if (Mode)
  {
    processbinmodecommand(_data);
  }
}

int main(void)
{

  //define port B for output
  DDRB = 0x1f;

  //define port C for input - Analog Reads
  DDRC = 0x00;

  USART_Init(UBRR_VALUE);
  InitADC();
  USART_Transmit_S("ADC Inited\r\n");

  starttime = millis();


  // put your main code here, to run repeatedly: the loop void in Arduino Code
  while (1)
  {
    updateTemp();
    //get command data until end of command reached
    unsigned int buffer_counter = 0;

    while (data != COMMAND_END)
    {
      data = USART_Receive();
      command[buffer_counter] = data;
      buffer_counter++;
    }

    processcommand(command);
    USART_Transmit_S(command);

    //    _delay_ms(1000);

    //Initialization the USART data buffer
    buffer_counter = 0;
    //clean the array of data
    while (buffer_counter <= buffersize)
    {
      command[buffer_counter] = 0;
      buffer_counter++;
    }
    //Initialization End of USART data Buffer
  }

  //evaluation start ellapsedtime case true for ellapsedtime update internal time
  ellapsedtime = millis() - starttime;

  ellapsedtime = ellapsedtime / 100;

  if (ellapsedtime >= 1)
  {
    timestamp = timestamp + ellapsedtime;
    starttime = millis();
  }
  //evaluation End ellapsedtime case true for ellapsedtime update internal time
}

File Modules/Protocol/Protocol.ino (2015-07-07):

#include <stdlib.h> 


#define ver "0_3_3"

#define buffersize 12

#define cooling 3
#define coolingin A0
#define heatsink A1

unsigned long ellapsedtime = 0;
unsigned long starttime = 0;

unsigned long internaltime = 0;

bool coolingstate = false;

float settemperature = 0;

float coolingtemperature = 0;
float heatsinktemperature = 0;

float exposure = 0;

String inString = "";


void setup()
{
  Serial.begin(9600);
  Serial.println("AltoEspectro - Start");
  starttime = millis();
}

void loop()
{

  char msg[buffersize] ;

  Serial.readBytesUntil(62, msg, buffersize);

  //  Serial.print(msg);Serial.print('\t');
  //  Serial.println(msg[3]);

  //AS+A <INIT>
  if (msg[3] == 65)
  {
    Serial.print("OK "); Serial.println(ver);
  }
  //DEBUG
  //AS+B <Set Time>
  //SET INTERNAL TIME
  if (msg[3] == 66)
  {
    Serial.print("OK ");
//    Serial.print(msg[5]);
//    Serial.print(msg[6]); 
//    Serial.print(msg[7]);
//    Serial.print(msg[8]);
//    Serial.print(msg[9]);
//    Serial.print(msg[10]);
//    Serial.print(msg[11]);
    
    for (int i = 5 ; i <= 11;i++)
    {
      inString += msg[i];
    }

    internaltime = inString.toInt();

    // internaltime = strtoul(inString,NULL,0);
    
//     Serial.println(inString);
    //    internaltime = (long)(msg[5] + msg[6] + msg[7] + msg[8] + msg[9] + msg[10] + msg[11]);

    Serial.println(internaltime);
  }
  //DEBUG
  //AS+C <Exposure Time>
  //GET SAMPLE DATA
  if (msg[3] == 67)
  {
    Serial.print("OK ");
    Serial.print(internaltime);
    Serial.print(' ');
    gettemperature();
    Serial.print(' ');
    Serial.print(exposure);
    Serial.print(' ');
    getexposure();
    Serial.println();
  }
  //AS+D
  //GET TEMPERATURE
  if (msg[3] == 68)
  {
    Serial.print("OK ");
    Serial.print(internaltime);
    Serial.print(' ');
    gettemperature();
    Serial.println();
  }

  //DEBUG
  //AS+E <ooling temperature>
  //SET TEMPERATURE
  if (msg[3] == 69)
  {
    Serial.print("OK ");
    coolingtemperature = (float)(msg[5] + msg[6] + msg[7] + msg[8] + msg[9] + msg[10] + msg[11]);
    Serial.print(coolingtemperature);
    Serial.println();
  }
  //AS+F <status>
  //SET COOLING ON/OFF
  if (msg[3] == 70)
  {
    Serial.print("OK");
    Serial.print(" ");
    Serial.print("STATUS: ");
    if (msg[5] == 79 && msg[6] == 78)
    {
      setcooling(true);
      coolingstate = true;
      Serial.print("ON");
    }
    if (msg[5] == 79 && msg[6] == 70 && msg[7] == 70)
    {
      setcooling(false);
      coolingstate = false;
      Serial.print("OFF");
    }
    Serial.println();
  }

  //AS+G
  //GET COOLING STATUS
  if (msg[3] == 71)
  {
    Serial.print("OK ");
    getcooling();
    Serial.println();
  }
  // Clear the Buffer
  for (int i = 0 ; i < buffersize; i++)
  {
    msg[i] = 0;
  }

  ellapsedtime = millis() - starttime;

  ellapsedtime = ellapsedtime / 100;

  if (ellapsedtime >= 1)
  {
    internaltime = internaltime + ellapsedtime;
    starttime = millis();
    //Serial.println(internaltime);
  }

}

void getexposure()
{
  Serial.print("data0 data1 .... dataN");
}

void gettemperature()
{
  Serial.print(coolingtemperature);
  Serial.print(' ');
  Serial.print(heatsinktemperature);
}

void setcooling(bool state)
{
  digitalWrite(cooling, state);
  coolingstate = state;
}

void getcooling()
{
  Serial.print("COOLING: ");
  if (coolingstate)
  {
    Serial.print("ON");
  }
  if (!coolingstate)
  {
    Serial.print("OFF");
  }
}

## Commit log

2015-06-25 Versão de Base
    Controlo do relógio do ILX544A, inicio do protocolo de comandos entre o
    cliente e o AVR
2015-06-26 Upload of the main Sketches for Arduino and Processing
    upload of the Sketches that enable the temperature readouts, and
    ILX544Aoutput readout, and the graphing by processing
2015-06-27 Introducção dos documentos sobre o formato FITS
    [hd38899.ods]
2015-06-27 SampleData
    introdução do ficheiro SampleData.txt com dados reais de um espectro,
    como se apresenta fotografia SampleData.PNG Para ser utilizado no
    desenvolvimento da aplicação ProcessingImager ou outra.
    [hd38899.csv]
2015-06-28 Actualização da documentação
    alteração dos ficheiros de doccumentação para o formato markdown
2015-06-28 Heatcalculation Document
    documento que explica as decisões tomadas na construção do sistema de
    dissipação de calor da camea
2015-07-01 Criação do Sketch para teste do control da fan
    Utiliza o Pin 6 para uma frequência de pwm de 980Hz de acordo com a
    datasheet do Atmega 328 e do código gerado pelo Arduino IDE para
    controlo de sinais PWM.
2015-07-01 Protocol Update
    Actualização do Protocolo de acordo com as necessidades encontradas na
    reunião de 30/06/2015
2015-07-02 Actualização do Protocolo de texto
    actualização do ficheiro da descrição do protocolo, e do sketch para
    Arduino.
2015-07-02 tentativa de resolução da apresentação do documento com markdown
2015-07-03 Upload dos Esquemáticos e das Boards
    [ILX544A_V1_B1.brd, ILX544A_V1_B1.sch, ILX544A_V1_B2.brd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]
2015-07-03 remoção justificada
    remoção devido à impossibilidade dos membros serem capazes de interagir
    com o sistema de modo coerente.
    [ILX544A_V1_B1.brd, ILX544A_V1_B1.sch, ILX544A_V1_B2.brd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]
2015-07-03 Upload Eagle Files, gerbers and drills
    [ILX544A_V1_B1.brd, ILX544A_V1_B1.sch, ILX544A_V1_B2.brd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]
2015-07-05 AltoEspectro - Firmware
    Implementação das funcionalidades de leitura de temperatura do peltier e
    do dissipador assim como da contagem de 1 millisegundo para actualização
    do timestamp.
2015-07-07 Stencils for Laser Printing V1_0
2015-07-07 Update com <BR> para resolver problema de apresentação no github
2015-07-07 Update do Protocolo
    inclusão do comando:
    - Get Status
    - Set Fan
2015-07-13 Folder Structure Changed
    Implementation of folder structure for Versioning
    [ILX544A_V1_B1.brd, ILX544A_V1_B1.sch, ILX544A_V1_B2.brd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]
2015-07-13 Correção ao esquemático
    Correção ao condensador da placa do sensor erro de tipografia
    [ILX544A_V1_B1.brd, ILX544A_V1_B1.sch, ILX544A_V1_B2.brd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]
2015-07-13 Introdução da versão 2 das boards
    [ILX544A_V2_B1.brd, ILX544A_V2_B1.sch]
2017-08-01 Make Eagle design files a subfolder of generic PCB design files
    [ILX544A_V1_B1.brd, ILX544A_V1_B1.sch, ILX544A_V1_B2.brd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]
2017-08-01 Add Kicad versions of PCB board design files
    [ILX544A_V1_B1.kicad_pcb, ILX544A_V1_B2.kicad_pcb, ILX544A_V2.kicad_pcb]
